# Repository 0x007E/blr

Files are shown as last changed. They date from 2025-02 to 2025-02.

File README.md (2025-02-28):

  

# `BLR` - Lead Battery Charger (Bleiakkuladeregler)

The `BLR` project is based on a pcb with a positive voltage regulator for battery charging (`PB137`). It can be used to charge [lead-batteries](#additional-information) with a voltage of 12V and observe the status of a battery during use.

| Experience | Level |
|:---|:-----:|
| Soldering | ?% |
| Mechanical  | ?% |

# Downloads

| Type | File | Description |
|:---:|:---:|:---|
| Simulation | [asc](https://github.com/0x007E/blr/raw/refs/heads/main/BLR.asc) | LTSpice Simulation | 
| Lochmaster | [lm4](https://github.com/0x007E/blr/raw/refs/heads/main/BLR.LM4) | Stripe grid circuit board | 
| Schematic | [pdf](https://github.com/0x007E/blr/releases/latest/download/schematic.pdf) / [cadlab](https://cadlab.io/project/28581/main/files) | Schematic files |
| Board | [pdf](https://github.com/0x007E/blr/releases/latest/download/pcb.pdf) / [cadlab](https://cadlab.io/project/28581/main/files) | Board file |
| Drill | [pdf](https://github.com/0x007E/blr/releases/latest/download/drill.pdf) | Drill file |
| PCB | [zip](https://github.com/0x007E/blr/releases/latest/download/kicad.zip) / [tar](https://github.com/0x007E/blr/releases/latest/download/kicad.tar.gz) | KiCAD/Gerber/BoM/Drill files |
| Mechanical | [zip](https://github.com/0x007E/blr/releases/latest/download/freecad.zip) / [tar](https://github.com/0x007E/blr/releases/latest/download/freecad.tar.gz) | FreeCAD/Housing and PCB (STEP) files |

# Hardware

There are two parts of the hardware. The pcb and the housing of the `BLR`. The pcb is created with `KiCAD` and the housing with `FreeCAD`. All files are built with `github actions` so that they are ready for a production environment. The housing is printed with a 3D-printer (`Dremel 3D40`).

## PCB

The circuit board is populated on both sides (Top, Bottom). The best way for soldering is within a vapor phase soldering system.

### Top Layer

Top Layer

### Bottom Layer

Bottom Layer

## Mechanical

The housing has a tolerance of `0.2mm` on each side of the case. So the pcb should fit perfectly in the housing. The tolerance can be modified with `FreeCAD` in the `Parameter` Spreadsheet.

### Assembled

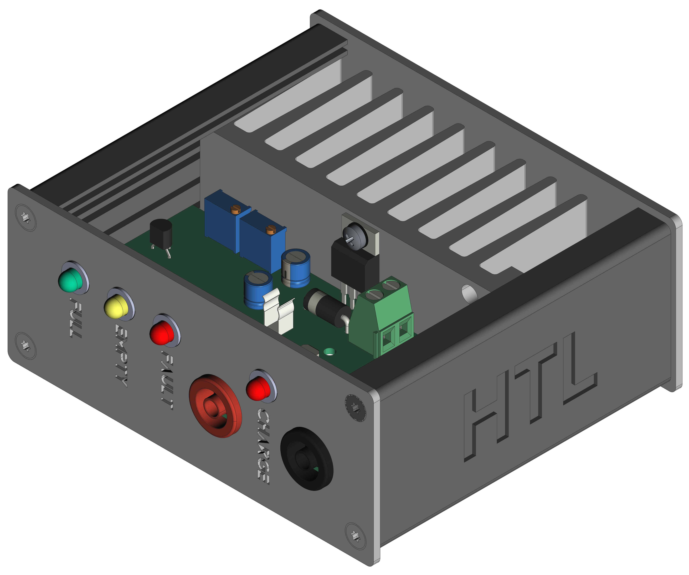
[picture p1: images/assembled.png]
Assembled


#### Exploded

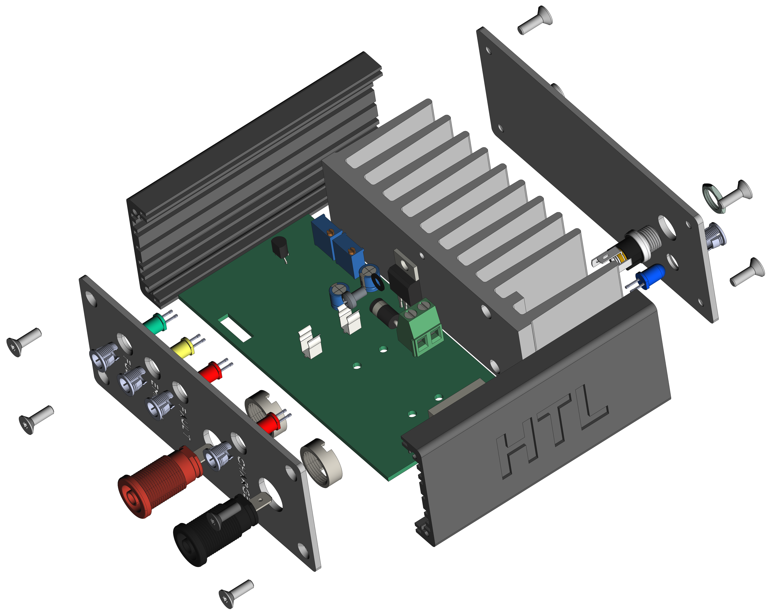
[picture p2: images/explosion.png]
Exploded


# Setup

To setup the `BLR` the reference voltages of `TP1`, `TP2`, `TP3` and `TP4` needs to be adjusted.

| Point | Voltage | U<sub>In</sub> |
|:-----:|:---:|:---:|
| `TP1` | ~2V5 | ~8V | 
| `TP2` | ~2V5 | - |
| `TP3` | ~2V5 | ~13V |

> TP4 needs to be adjusted manually with an Ampermeter. If the current is > `100 mA` the charging LED (`J8`) should be on. This behaviour can be adjusted through `RV3`.

# Additional Information

| Type | Link | Description |
|:---:|:---:|:---|
| PB137 | [pdf](https://www.st.com/resource/en/datasheet/pb137.pdf) | Positive voltage regulator for battery charging datasheet |
| TL431 | [pdf](https://www.ti.com/lit/ds/symlink/tl431.pdf) | Precision voltage reference |
| LM358 | [pdf](https://www.ti.com/lit/ds/symlink/lm358.pdf) | Dual operational amplifier |
| Battery | [web](https://at.rs-online.com/web/p/bleiakkus/8431310) | Lead battery with 12V |

---

R. GAECHTER

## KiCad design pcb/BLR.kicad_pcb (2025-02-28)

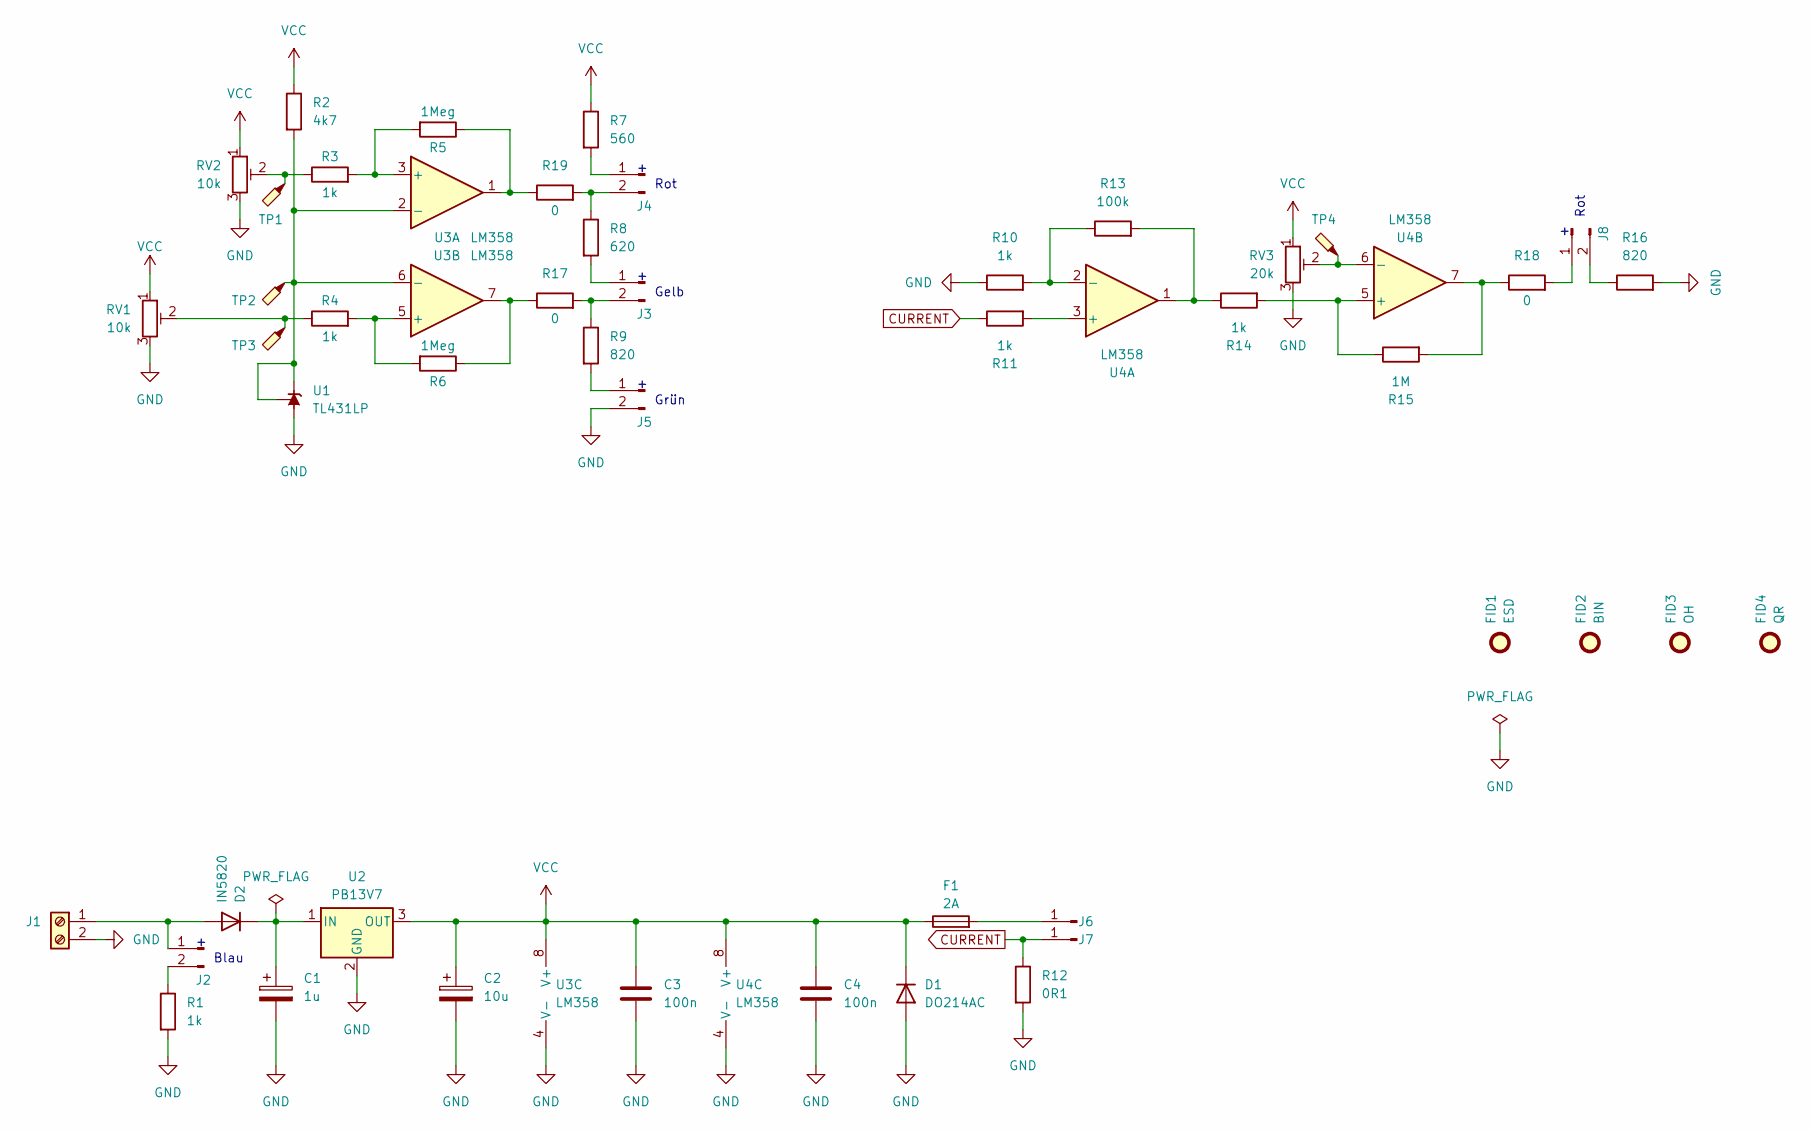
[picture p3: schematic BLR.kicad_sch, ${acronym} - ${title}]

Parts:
C1: 1u; CP_Radial_D6.3mm_P2.50mm
C2: 10u; CP_Radial_D6.3mm_P2.50mm
C3, C4: 100n; C_1206_3216Metric
D1: DO214AC; D_MELF
D2: IN5820; D_DO-201AD_P12.70mm_Horizontal
F1: 2A; Fuseholder_Clip-5x20mm_Littelfuse_111_Inline_P20.00x5.00mm_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
FID1: ESD; ESD-Logo_6.6x6mm_SilkScreen
FID2: BIN; WEEE-Logo_4.2x6mm_SilkScreen
FID3: OH; OSHW-Logo_5.7x6mm_SilkScreen
FID4: QR; QR_0x007e
J1: Screw_01x02; TerminalBlock_Phoenix_MKDS-1,5-2-5.08_1x02_P5.08mm_Horizont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
J2, J3, J4, J5, J8: Conn_01x02_Pin; WAGO_2060-402_998-404
J6, J7: Conn_01x01_Pin; CONN_QC_RCPT_0.250
R1, R3, R4, R10, R11, R14: 1k; R_1206_3216Metric
R2: 4k7; R_1206_3216Metric
R5, R6: 1Meg; R_1206_3216Metric
R7: 560; R_1206_3216Metric
R8: 620; R_1206_3216Metric
R9, R16: 820; R_1206_3216Metric
R12: 0R1; R_Axial_Power_L20.0mm_W6.4mm_P22.40mm
R13: 100k; R_1206_3216Metric
R15: 1M; R_1206_3216Metric
R17, R18, R19: 0; R_1206_3216Metric
RV1, RV2: 10k; Potentiometer_Bourns_3296W_Vertical
RV3: 20k; Potentiometer_Bourns_3314J_Vertical
TP1, TP2, TP3, TP4: TestPoint_Probe; TestPoint_Pad_D1.5mm
U1: TL431LP; TO-92_Wide
U2: PB13V7; TO-220-3_Vertical
U3, U4: LM358; SOP-8_3.9x4.9mm_P1.27mm

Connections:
CURRENT: J7.1, R11.1, R12.1
GND: C1.2, C2.2, C3.2, C4.2, D1.2 (A), J1.2, J5.2, R1.2, R10.1, R12.2, R16.2, RV1.3, RV2.3, RV3.3, U1.2 (A), U2.2 (GND), U3.4 (V-), U4.4 (V-)
unnamed: D2.2 (A), J1.1, J2.1
unnamed: C1.1, D2.1 (K), U2.1 (IN)
unnamed: J2.2, R1.1
unnamed: J3.1, R8.2
unnamed: J3.2, R9.1, R17.2
unnamed: J4.1, R7.2
unnamed: J4.2, R8.1, R19.2
unnamed: J5.1, R9.2
unnamed: F1.2, J6.1
unnamed: J8.1, R18.2
unnamed: J8.2, R16.1
unnamed: R3.1, RV2.2, TP1.1
unnamed: R4.1, RV1.2, TP3.1
unnamed: R13.2, R14.1, U4.1
unnamed: R15.2, R18.1, U4.7
unnamed: R6.1, R17.1, U3.7
unnamed: R5.1, R19.1, U3.1
unnamed: R2.2, TP2.1, U1.1 (REF), U1.3 (K), U3.2 (-), U3.6 (-)
unnamed: R3.2, R5.2, U3.3 (+)
unnamed: R4.2, R6.2, U3.5 (+)
unnamed: R11.2, U4.3 (+)
unnamed: R10.2, R13.1, U4.2 (-)
unnamed: R14.2, R15.1, U4.5 (+)
unnamed: RV3.2, TP4.1, U4.6 (-)
VCC: C2.1, C3.1, C4.1, D1.1 (K), F1.1, R2.1, R7.1, RV1.1, RV2.1, RV3.1, U2.3 (OUT), U3.8 (V+), U4.8 (V+)

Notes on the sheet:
Rot
Blau
Gelb
Grün

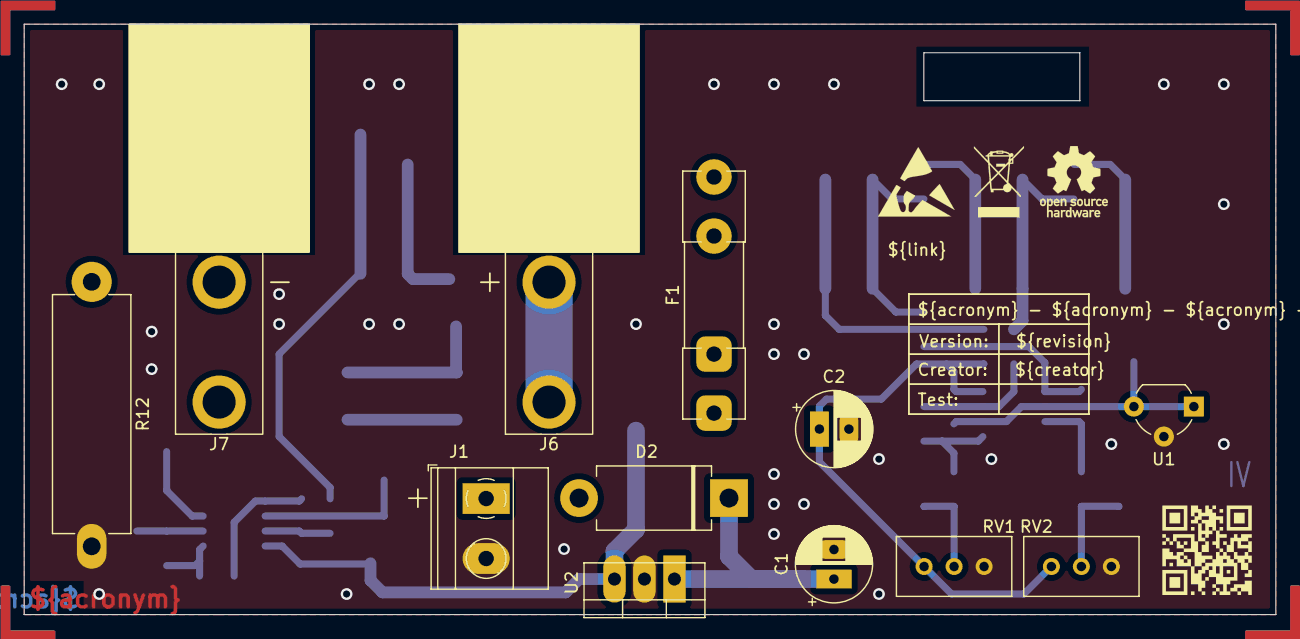
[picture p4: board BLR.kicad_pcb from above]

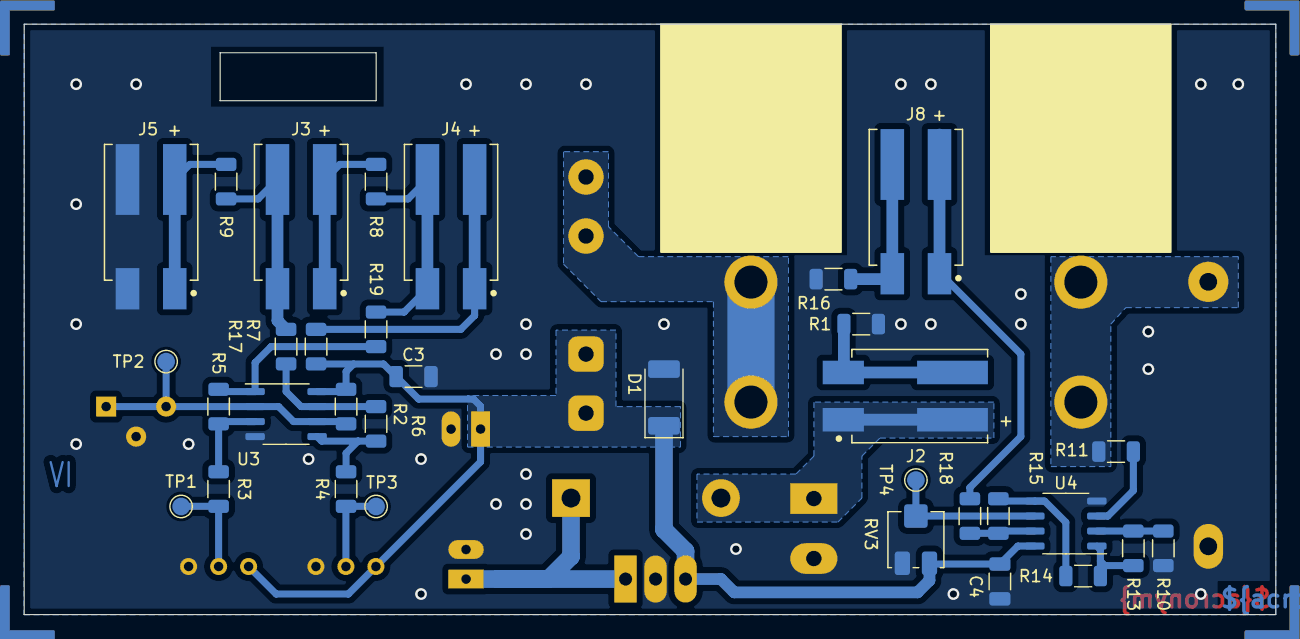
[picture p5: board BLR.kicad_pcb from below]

Board: 2 copper layers, 106.0 x 50.0 mm, 49 parts (33 on the bottom side), 27 nets.

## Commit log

2024-10-21 Add missing filter
2025-02-28 Case refactoring
2025-02-28 Add value to BOM
2025-02-28 Remove wrong identifier
    [BLR.kicad_pcb]
2025-02-28 Add extended dimensioning
    [BLR.kicad_pcb]
2025-10-22 Change supply voltage value

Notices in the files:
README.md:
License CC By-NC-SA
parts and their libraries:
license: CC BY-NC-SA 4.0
